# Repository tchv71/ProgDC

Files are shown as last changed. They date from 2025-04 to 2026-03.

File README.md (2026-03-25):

## Программируемый дешифратор (MMU) для Пальмиры

Прототипом послужил программируемый дешифратор для Радио 86-РК, описанный в журналах "Радио" 1994, №3-5. 

[https://archive.radio.ru/web/1994/03/020/]: https://archive.radio.ru/web/1994/03/020/

Общая идея конструктива - плата программируемого дешифратора вставляется в сокет процессора, а процессор (возможно, в виде z80card) вставляется в панельку на плате ПД. Дополнительные сигналы к/от платы Пальмиры выводятся на штырьковый разъем на правом краю платы ПД.

Внесены следующие усовершенствования:

1. Устранена зависимость от значений системного регистра при программировании устройства по адресу 0FFh. В оригинальном устройстве запись по адресу 0FFh меняла и значение системного регистра, и ОЗУ дешифратора. Это налагало ограничение на значения, которые можно записать в порт 0FFh и усложняло программирование. Теперь эти порты схемотехнически разделены - если было предварительное чтение из порта 0FFh, запись будет в системный регистр, в противном случае - в ОЗУ дешифратора.
2. Используются все биты ОЗУ дешифратора, старшие 4 бита используются для расширения адреса системного ОЗУ. Поддерживается до 512К системного ОЗУ. Поддерживается 64 (максимум 128) кбайта ПЗУ.
3. Бит 4 ОЗУ дешифратора более не используется как признак "только чтение", вместо него используется значение 3 номера линии устройства.
4. Поддерживается бит 0 байта расширения конфигурации Пальмиры, включающий теневое ОЗУ по адресам 0-7FFFh.
5. Поддерживается до 4-х конфигураций дешифратора, которые выбираются битами 4-3 системного регистра. Таким образом, для того, чтобы изменить конфигурацию памяти, нет необходимости менять её постранично, можно запрограммировать новую конфигурацию заранее, а потом мгновенно применить её одной запись в порт 0FFh.
6. Поддерживается процессор Z80 в формате z80-card. 580ВМ80А также поддерживается, совместно с системным контроллером 580ВК38
7. Вместо микросхемы КР537РУ10 применена IDC6116SA45P как более быстродействующая, изменены тайминги сигнала записи в нее для повышения надежности записи.

## Системный регистр (in/out 0FFh)

|Бит|Обозначение|Биты управления режимом|
|-|-|-|
|7|Q7|Работа|
|6|Q6|Программирование портов ввода-вывода|
|5|Q5|Программирование конфигурации памяти|
|4||Биты выбора конфигурации (запись) Бит1|
|3||Биты выбора конфигурации (запись) Бит0|
|2||Биты выбора конфигурации (чтение) Бит1|
|1||Биты выбора конфигурации (чтение) Бит0|
|0||свободно|

Чтобы записать в системный регистр, надо сначала из него прочитать. Первая запись после чтения по адресу 0FFh будет в системный регистр, все последующие - в ОЗУ дешифратора (в режиме программирования) или в порт в рабочем режиме.

## Назначение линий выхода дешифратора ИД3:

|Номер линии|Адрес в Пальмире|Устройство|
|-|-|-|
|0|0C200h|ВВ55 контроллер клавиатуры|
|1|0C400h|ВВ55 дополнительный контроллер|
|2|0C000h|ВГ75 контроллер дисплея|
|3|-|ОЗУ только чтение|
|4|0E000h|ПЗУ|
|5|0000h|ОЗУ первые 32кб|
|6|0CC00h|ВИ53-1|
|7|0C600h|ВТ57/ВТ37|
|8|0C800h|ВИ53-2|
|9|||
|10|0D800h|ОЗУ ЗГ РУ10|
|11|0CE00h|Palmira ext. byte|
|12|0C300h|FT245R port|
|13|8000h|ОЗУ вторые 32кб|
|14|0CA00h|VDP TMS9918A|
|15|0F700h|Страница контроллеров RK60k|

Линия 15 задает положения страницы контроллеров RK60k размером 256 байт. Контроллеры имеют следующие фиксированные относительные адреса:

|Номер|Контроллер|Адрес|
|-|-|-|
|0|FDC |0F700h; 1793 floppy disk controller|
|1|INTR|0F720h; 8259 interrupt controller |
|2|PSG1|0F740h; 8253 first	 |
|3|PSG2|0F760h; 8253 second	 	 |
|4|PPI |0F780h; 8255 fist		 |
|5|PPI2|0F7A0h; 8255 second	 	  |
|6|DISP|0F7C0h; 8275 display adapter	 |
|7|DMA |0F7E0h; 8257 DMA chip	 	 |

Поскольку одна конфигурация занимает 512 байт в ОЗУ дешифратора, появляется возможность хранить 4 конфигурации и мгновенно переключать их битами 3 и 4 системного регистра.

## ПЗУ 556РТ4

| Бит адреса | Сигнал |
| --- | --- |
| A3 | Q7 |
| A2 | Q6 |
| A1 | Q5 |
| A0 | In/Out |

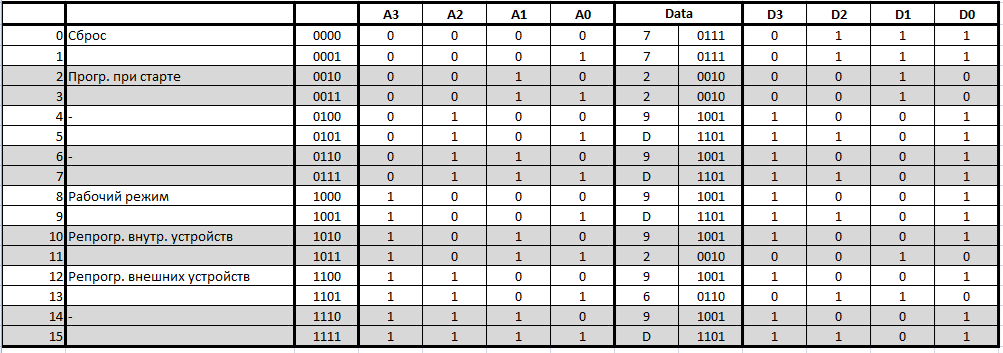
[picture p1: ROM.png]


## Ошибки в печатных платах:

### Версия 1.4:

1. На микросхему D10 6116SA45P не заведено питание и земля.
2. Вывод 8 В14.3 К555ЛА3 должен быть подключен к выводу 15 D9 КР556РТ4, а вывод 4 D9 - к земле.

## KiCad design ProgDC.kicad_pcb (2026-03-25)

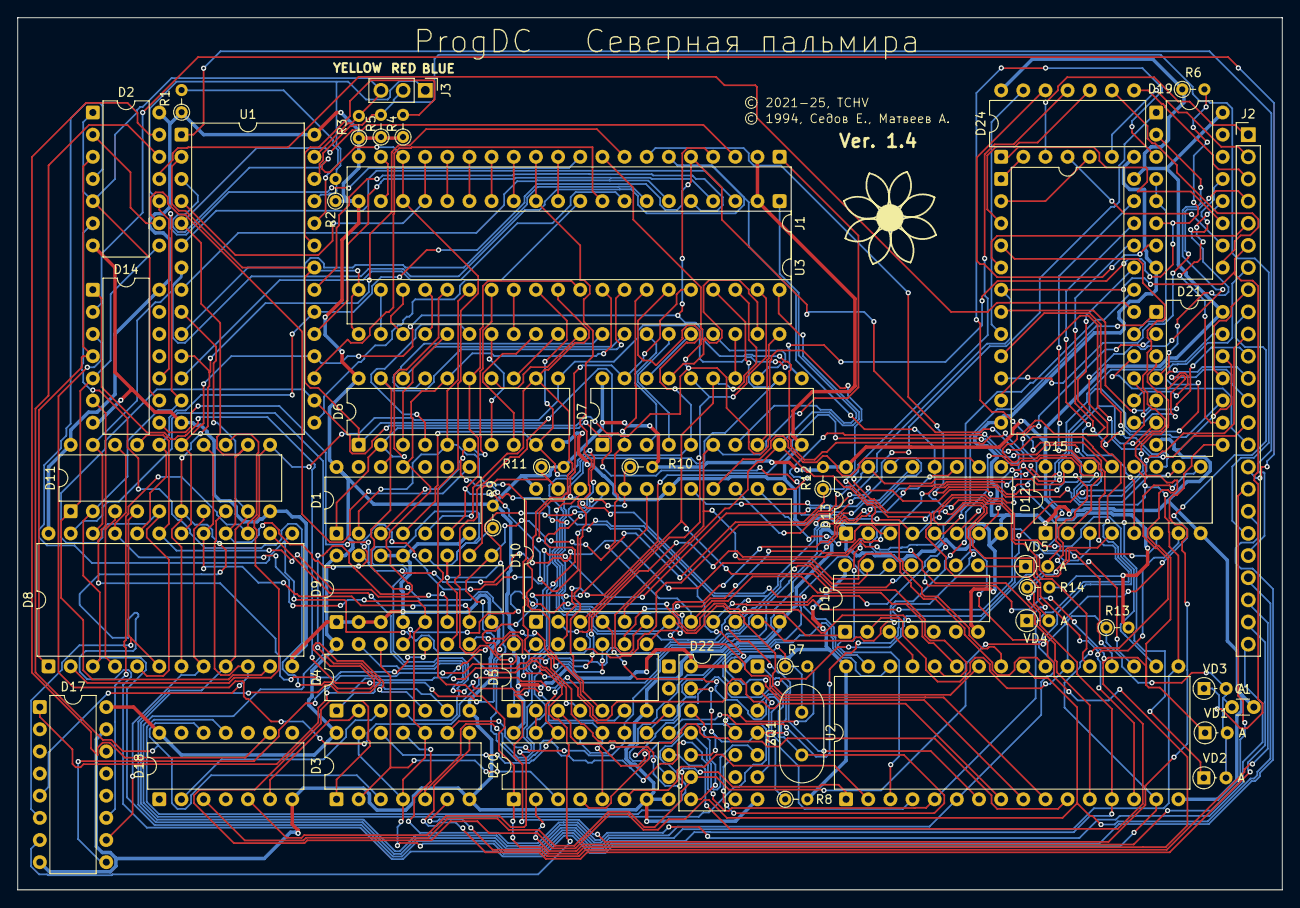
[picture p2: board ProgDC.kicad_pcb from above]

Board: 2 copper layers, 145.0 x 100.0 mm, 51 parts (1 on the bottom side), 179 nets.

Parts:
C1: 470; C_Disc_D3.0mm_W1.6mm_P2.50mm
D1: K155LA2; DIP-14_W7.62mm
D2, D4, D16: 133LL1; DIP-14_W7.62mm
D3, D20, D24: 133LI1; DIP-14_W7.62mm
D5, D22: 133LN1; DIP-14_W7.62mm
D6, D7, D11: 1533ИР22; DIP-20_W7.62mm
D8: К589ИР12; DIP-24_W15.24mm
D9: КР556РТ4; DIP-16_W7.62mm
D10: КР537РУ10; DIP-24_W15.24mm
D12, D13: K589АП16; DIP-16_W7.62mm
D14: 133LA3; DIP-14_W7.62mm
D15: 155ID3; DIP-24_W15.24mm
D17: КР1533КП11; DIP-16_W7.62mm
D18, D23: 555TM2; DIP-14_W7.62mm
D19: 74AC138(COMB); DIP-16_W7.62mm
D21: 74HC86N; DIP-14_W7.62mm
J1: Conn_02x20_Counter_Clockwise_MountingPin; DIP-40_W15.24mm
J2: Conn_01x24_Pin; PinHeader_1x24_P2.54mm_Vertical
J3: Conn_01x03_Pin; PinHeader_1x03_P2.54mm_Vertical
R1, R2, R3, R4, R5, R6, R9, R10, R11, R12, R13, R14: R0125; R_Axial_DIN0204_L3.6mm_D1.6mm_P2.54mm_Vertical
R7, R8: R0125H; R_Axial_DIN0204_L3.6mm_D1.6mm_P2.54mm_Vertical
U1: KR580VK28; DIP-28_W15.24mm
U2: 628512; DIP-32_W15.24mm
U3: CPU; DIP-40_W15.24mm
VD1, VD2, VD3, VD4, VD5: 1N4148; D_DO-34_SOD68_P2.54mm_Vertical_AnodeUp
ZQ1: QUARTZ; Crystal_HC18-U_Vertical

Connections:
+5V: D1.14 (VCC), D2.14 (VCC), D3.14 (VCC), D4.14 (VCC), D5.14 (VCC), D6.20 (VCC), D7.20 (VCC), D8.24 (VCC), D9.16 (+5V), D10.24 (VCC), D11.20 (VCC), D12.16 (VCC), D13.16 (VCC), D14.14 (VCC), D15.24 (VCC), D16.14 (VCC), D17.16 (VCC), D18.14 (VCC), D19.16 (VCC), D20.14 (VCC), D21.14 (VCC), D22.14 (VCC), D23.14 (VCC), D24.14 (VCC), J1.20, R1.1 (TOP), R2.1 (TOP), R3.1 (TOP), R4.1 (TOP), R5.1 (TOP), R6.1 (TOP), R8.2, R9.2 (BOT), R10.2 (BOT), R11.2 (BOT), R12.2 (BOT), R13.2 (BOT), R14.2 (BOT), U1.28 (VCC), U2.32 (VCC), U3.20 (VCC)
/8MHZ: D18.11 (C), D23.5 (Q), D23.11 (C)
/"1": D6.11 (PE), D7.11 (PE), D8.2 (MD), D11.11 (PE), D19.6 (E1), R6.2 (BOT)
/+12V: J1.28, U3.28 (+12V)
/-5V: J1.11, U3.11 (-5V)
/A0: D6.3 (D0), U3.25 (A0)
/A1: D6.4 (D1), U3.26 (A1)
/A2: D6.7 (D2), U3.27 (A2)
/A3: D6.8 (D3), U3.29 (A3)
/A4: D6.13 (D4), U3.30 (A4)
/A5: D6.14 (D5), U3.31 (A5)
/A6: D6.17 (D6), U3.32 (A6)
/A7: D6.18 (D7), U3.33 (A7)
/A8: D7.3 (D0), U3.34 (A8)
/A9: D7.4 (D1), U3.35 (A9)
/A10: D7.7 (D2), U3.1 (A10)
/A11: D7.8 (D3), U3.40 (A11)
/A12: D7.13 (D4), U3.37 (A12)
/A13: D7.14 (D5), U3.38 (A13)
/A14: D7.17 (D6), U3.39 (A14)
/A15: D7.18 (D7), U3.36 (A15)
/AB0: D1.1, D6.2 (Q0), J1.25, U2.12 (A0)
/AB1: D1.2, D6.5 (Q1), J1.26, U2.11 (A1)
/AB2: D1.3, D6.6 (Q2), J1.27, U2.10 (A2)
/AB3: D1.4, D6.9 (Q3), J1.29, U2.9 (A3)
/AB4: D1.5, D6.12 (Q4), J1.30, U2.8 (A4)
/AB5: D1.6, D6.15 (Q5), D19.1 (0), J1.31, U2.7 (A5)
/AB6: D1.11, D6.16 (Q6), D19.2 (1), J1.32, U2.6 (A6)
/AB7: D1.12, D6.19 (Q7), D19.3 (2), J1.33, U2.5 (A7)
/AB8: D7.2 (Q0), D10.8 (A10), J1.34, U2.27 (A8)
/AB9: D7.5 (Q1), D10.7 (A9), J1.35, U2.26 (A9)
/AB10: D7.6 (Q2), D10.6 (A8), J1.1, U2.23 (A10)
/AB11: D7.9 (Q3), D10.5 (A7), J1.40, U2.25 (A11)
/AB12: D7.12 (Q4), D10.4 (A6), J1.37, U2.4 (A12)
/AB13: D7.15 (Q5), D10.3 (A5), J1.38, U2.28 (A13)
/AB14: D7.16 (Q6), D10.2 (A4), J1.39
/AB15: D7.19 (Q7), D10.1 (A3), J1.36, U2.31 (A15)
/ARR16: D20.6 (Y), U2.2 (A16)
/ARR17: D20.8 (Y), U2.30 (A17)
/ARR18: D20.11 (Y), U2.1 (A18)
/C1: J1.22, U3.22 (C1)
/C2: J1.15, U3.15 (C2)
/C800_VI53_2: D5.13 (A), D21.8 (Y)
/CLK: D18.3 (C), D23.9 (Q), J2.9
/CS_RAMR: D16.12 (A), D22.6 (Y)
/D0: U1.15 (D0), U3.10 (D0)
/D1: U1.17 (D1), U3.9 (D1)
/D2: U1.12 (D2), U3.8 (D2)
/D3: U1.10 (D3), U3.7 (D3)
/D4: U1.6 (D4), U3.3 (D4)
/D5: U1.19 (D5), U3.4 (D5)
/D6: U1.21 (D6), U3.5 (D6)
/D7: U1.8 (D7), U3.6 (D7)
/DB0: D8.3 (D0), D11.2 (Q0), D12.4 (DI0), J1.10, U1.13 (DB0), U2.13 (D0)
/DB1: D8.5 (D1), D11.5 (Q1), D12.7 (DI1), J1.9, U1.16 (DB1), U2.14 (D1)
/DB2: D8.7 (D2), D11.6 (Q2), D12.9 (DI2), J1.8, U1.11 (DB2), U2.15 (D2)
/DB3: D8.9 (D3), D11.9 (Q3), D12.12 (DI3), J1.7, U1.9 (DB3), U2.17 (D3)
/DB4: D8.16 (D4), D11.12 (Q4), D13.4 (DI0), J1.3, U1.5 (DB4), U2.18 (D4)
/DB5: D8.18 (D5), D11.15 (Q5), D13.7 (DI1), J1.4, U1.18 (DB5), U2.19 (D5)
/DB6: D8.20 (D6), D11.16 (Q6), D13.9 (DI2), J1.5, U1.20 (DB6), U2.20 (D6)
/DB7: D8.22 (D7), D11.19 (Q7), D13.12 (DI3), J1.6, U1.7 (DB7), U2.21 (D7)
/DBIN: J1.17, U1.4 (DBIN), U3.17 (RC)
/HLD: J1.13, U3.13 (HLD)
/HLDA: D5.1 (A), D6.1 (~EO), D7.1 (~EO), J1.21, U1.2 (HLDA), U1.22 (BUSEN), U3.21 (HLDA)
/INT: J1.14, U3.14 (INT)
/INTE: J1.16, U3.16 (INTE)
/P0: D4.4 (A), D9.12 (D0), R9.1 (TOP)
/P1: D4.9 (A), D9.11 (D1), D10.20 (~OE), R10.1 (TOP)
/P2: D9.10 (D2), D10.23 (A2), R11.1 (TOP)
/P3: D9.9 (D3), D12.15 (~CE), D13.15 (~CE), D17.1 (SEL), R12.1 (TOP)
/Q0: D8.4 (Q0), D11.3 (D0)
/Q1: D8.6 (Q1), D11.4 (D1), D17.6 (2B)
/Q2: D8.8 (Q2), D11.7 (D2), D17.10 (3B)
/Q3: D8.10 (Q3), D11.8 (D3), D17.5 (2A)
/Q4: D8.15 (Q4), D11.13 (D4), D17.11 (3A)
/Q5: D8.17 (Q5), D9.7 (A2), D11.14 (D5)
/Q6: D8.19 (Q6), D9.6 (A1), D11.17 (D6)
/Q7: D3.4 (A), D3.10 (B), D3.13 (B), D8.21 (Q7), D9.5 (A0), D11.18 (D7), J2.18
/R0: D12.2 (DO0), D15.23 (1)
/R1: D12.5 (DO1), D15.22 (2)
/R2: D12.11 (DO2), D15.21 (4)
/R3: D12.14 (DO3), D15.20 (8)
/R4: D13.2 (DO0), U2.3 (A14)
/R5: D3.5 (B), D13.5 (DO1), D21.1 (A)
/R6: D3.9 (A), D13.11 (DO2), D20.9 (A)
/R7: D3.12 (A), D13.14 (DO3), D20.12 (A)
/R8: D14.3 (Y), D22.3 (A)
/RAM_SEL: D14.2 (B), J2.16
/RDY: J1.23, U3.23 (RDY)
/RESET: D5.5 (A), J1.12, U3.12 (RST)
/ROM_A13: D3.6 (Y), J2.22
/ROM_A14: D3.8 (Y), J2.23
/ROM_A15: D3.11 (Y), J2.24
/STSTB: J2.20, U1.1 (STSTB)
/SYN: J1.19, U3.19 (SYN)
/WI: J1.24, U3.24 (WI)
/~A_FF: D1.8, D2.2 (B), D2.9 (A)
/~C100_SD_CNTR: D15.10 (9), J2.4
/~C200_PPI1_: D24.3 (Y), J2.1
/~C200_PPI1: D15.1 (0), D24.2 (B)
/~C300: D15.14 (12), J2.13
/~C400_PPI2_: D24.6 (Y), J2.2
/~C400_PPI2: D15.2 (1), D24.5 (B)
/~C500_VDP: D15.16 (14), J2.15
/~C800_VI53_2_: D5.12 (Y), J2.10
/~C800_VI53_2: D15.9 (8), D21.10 (B)
/~CC00_VI53_1_: D5.8 (Y), J2.7
/~CC00_VI53_1: D15.7 (6), D21.5 (B)
/~CE00: D15.13 (11), J2.12
/~CS_628512: C1.1, D16.2 (B), R13.1 (TOP), U2.22 (CS), VD1.2 (A), VD2.2 (A), VD3.2 (A)
/~CS_D800: D15.11 (10), J2.14
/~CS_DMA_2: D21.11 (Y), J2.8
/~CS_DMA_: D24.11 (Y), VD4.1 (K)
/~CS_DMA: D15.8 (7), D24.13 (B)
/~CS_RAMR: D15.4 (3), D16.10 (B), D22.5 (A), VD1.1 (K)
/~CS_ROM: D15.5 (4), J2.5
/~CS_SRAM_8000: D15.15 (13), J2.11, VD2.1 (K)
/~CS_VG75_: D24.8 (Y), J2.3
/~CS_VG75: D15.3 (2), D24.10 (B)
/~D15_CS1: D4.8 (Y), D15.19 (&C)
/~D15_CS2: D2.11 (Y), D15.18 (C)
/~F700: D15.17 (15), D19.4 (~E2), D19.5 (~E3)
/~INTA: R4.2 (BOT), U1.23 (INTA)
/~I/OR: D2.10 (B), D14.10 (B), J3.1, R2.2 (BOT), U1.25 (I/OR)
/~I/OW: D2.1 (A), D2.5 (B), D14.9 (A), J3.3, R3.2 (BOT), U1.27 (I/OW)
/~MEMR: R1.2 (BOT), U1.24 (MEMR)
/~MEMW_VT57: D20.2 (B), J2.17
/~MEMW: J2.19, J3.2, R5.2 (BOT), U1.26 (MEMW)
/~MWR: D3.2 (B), D4.12 (A), D20.3 (Y)
/~RAM_MAIN: D5.11 (A), D15.6 (5), J2.6, VD3.1 (K)
/~RD: D3.1 (A), J2.21, U2.24 (RD)
/~RESET: D5.6 (Y), D8.14 (RES)
/~WE_628512: D4.11 (Y), D16.1 (A)
/~WR: D16.9 (A), D20.1 (A), J1.18, U1.3 (WR), U3.18 (TR)
GND: C1.2, D1.7 (GND), D2.7 (GND), D3.7 (GND), D4.7 (GND), D5.7 (GND), D6.10 (GND), D7.10 (GND), D8.12 (GND), D9.1 (A6), D9.2 (A5), D9.3 (A4), D9.4 (A3), D9.8 (GND), D9.13 (~CS1), D9.14 (~CS2), D10.12 (GND), D10.18 (~CS), D11.10 (GND), D12.1 (~CS), D12.8 (GND), D13.1 (~CS), D13.8 (GND), D14.7 (GND), D15.12 (GND), D16.7 (GND), D17.8 (GND), D17.15 (~OE), D18.7 (GND), D19.8 (GND), D20.7 (GND), D21.7 (GND), D21.12 (A), D22.7 (GND), D23.7 (GND), D24.7 (GND), J1.2, U1.14 (GND), U2.16 (GND), U3.2 (GND)
unnamed: D2.4 (A), D5.4 (Y), D8.13 (CS2)
unnamed: D2.6 (Y), D4.5 (B)
unnamed: D4.1 (A), D4.6 (Y)
unnamed: D5.3 (A), D8.23 (S1)
unnamed: D10.19 (A0), D17.9 (3Y)
unnamed: D10.22 (A1), D17.7 (2Y)
unnamed: D10.9 (D0), D12.3 (DB0)
unnamed: D10.10 (D1), D12.6 (DB1)
unnamed: D10.11 (D2), D12.10 (DB2)
unnamed: D10.13 (D3), D12.13 (DB3)
unnamed: D10.14 (D4), D13.3 (DB0)
unnamed: D10.15 (D5), D13.6 (DB1)
unnamed: D10.16 (D6), D13.10 (DB2)
unnamed: D10.17 (D7), D13.13 (DB3)
unnamed: D10.21 (~WE), D18.5 (Q)
unnamed: D2.8 (Y), D8.11 (EV), D11.1 (~EO), D14.5 (B)
unnamed: D5.10 (Y), D14.1 (A)
unnamed: D2.3 (Y), D8.1 (CS1), D14.4 (A)
unnamed: D4.10 (B), D14.6 (Y)
unnamed: D9.15 (A7), D14.8 (Y), D16.13 (B)
unnamed: D16.3 (Y), U2.29 (WR)
unnamed: D16.8 (Y), VD5.1 (K)
unnamed: D4.13 (B), D16.11 (Y)
unnamed: D4.3 (Y), D18.2 (D)
unnamed: D4.2 (B), D18.6 (~Q)
unnamed: D2.12 (A), D3.3 (Y), D18.12 (D)
unnamed: D2.13 (B), D18.9 (Q)
unnamed: D19.12 (3), D21.9 (A)
unnamed: D19.11 (4), D24.1 (A)
unnamed: D19.10 (5), D24.4 (A)
unnamed: D19.9 (6), D24.9 (A)
unnamed: D20.4 (A), D21.3 (Y)
unnamed: D5.2 (Y), D20.5 (B), D20.10 (B), D20.13 (B)
unnamed: D21.2 (B), D22.4 (Y)
unnamed: D19.13 (2), D21.4 (A)
unnamed: D5.9 (A), D21.6 (Y)
unnamed: D21.13 (B), R14.1 (TOP), VD4.2 (A), VD5.2 (A)
unnamed: D22.11 (A), D22.12 (Y), R7.2
unnamed: D22.10 (Y), D23.3 (C), ZQ1.1
unnamed: D22.13 (A), R7.1, ZQ1.2
unnamed: D23.2 (D), D23.6 (~Q)
unnamed: D23.1 (~R), D23.4 (~S), D23.10 (~S), D23.13 (~R)
unnamed: D23.8 (~Q), D23.12 (D)
unnamed: D19.7, D24.12 (A)

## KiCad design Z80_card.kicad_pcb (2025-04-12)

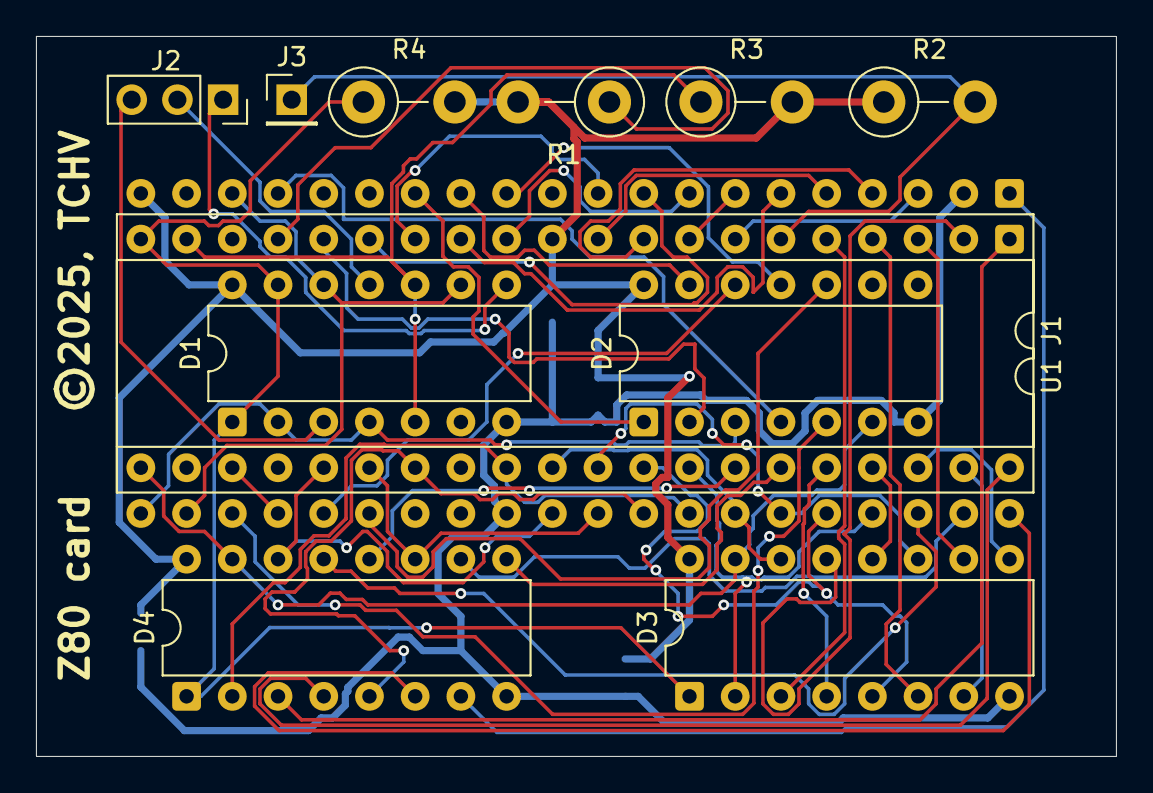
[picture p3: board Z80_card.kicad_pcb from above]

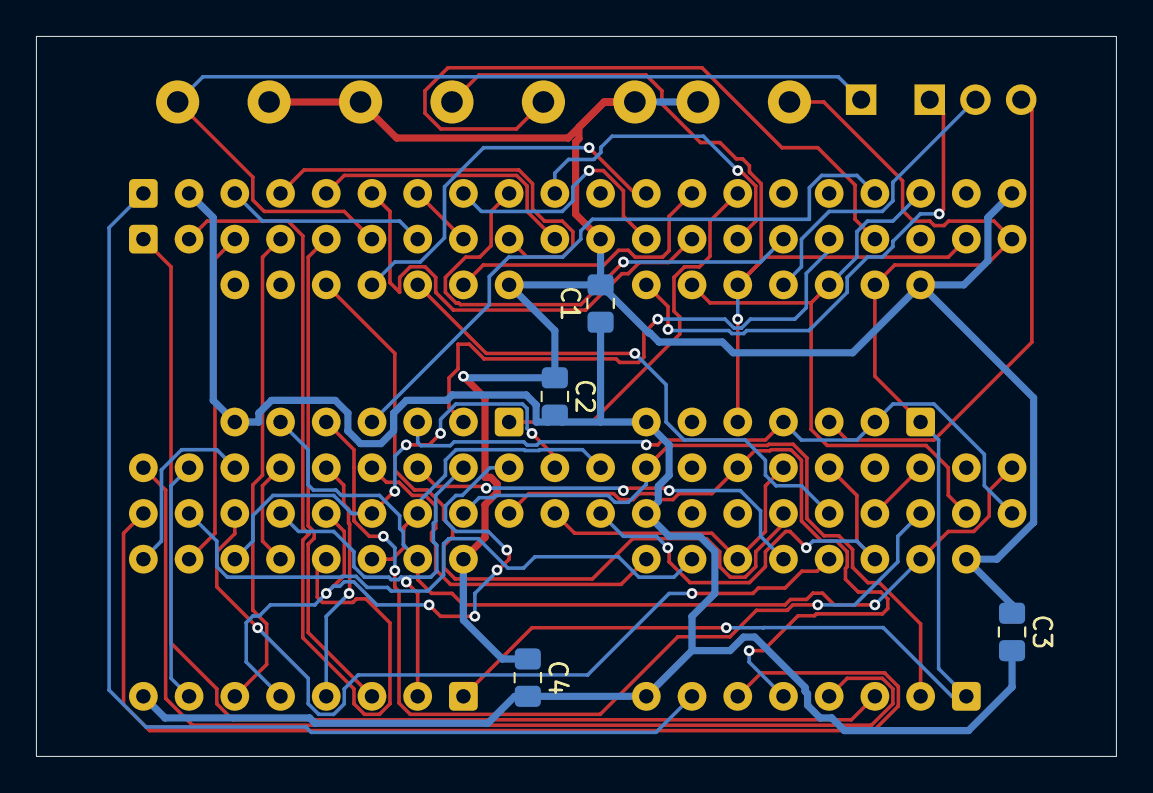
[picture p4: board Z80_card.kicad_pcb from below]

Board: 2 copper layers, 60.0 x 40.0 mm, 16 parts (4 on the bottom side), 53 nets.

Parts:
C1, C2, C3, C4: C; C_0805_2012Metric_Pad1.18x1.45mm_HandSolder
D1: 133LL1; DIP-14_W7.62mm
D2: 133LN1; DIP-14_W7.62mm
D3, D4: КР1533КП11; DIP-16_W7.62mm
J1: Conn_02x20_Counter_Clockwise_MountingPin; DIP-40_W15.24mm
J2: Conn_01x03_Pin; PinSocket_1x03_P2.54mm_Vertical
J3: Conn_01x01_Pin; PinHeader_1x01_P2.54mm_Vertical
R1, R2, R3, R4: R0125; R_Axial_DIN0411_L9.9mm_D3.6mm_P5.08mm_Vertical
U1: Z84C00-4SC; DIP-40_W15.24mm

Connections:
+5V: C1.2, C2.1, C3.1, C4.1, D1.14 (VCC), D2.14 (VCC), D3.16 (VCC), D4.16 (VCC), J1.20, R1.2 (BOT), R2.1 (TOP), R3.2 (BOT), R4.2 (BOT), U1.11 (VCC)
/A0: D4.14 (4A), J1.25, U1.30 (A0)
/A1: D4.11 (3A), J1.26, U1.31 (A1)
/A2: D4.5 (2A), J1.27, U1.32 (A2)
/A3: D4.2 (1A), J1.29, U1.33 (A3)
/A4: D3.14 (4A), J1.30, U1.34 (A4)
/A5: D3.11 (3A), J1.31, U1.35 (A5)
/A6: D3.5 (2A), J1.32, U1.36 (A6)
/A7: D3.2 (1A), J1.33, U1.37 (A7)
/A8: D4.12 (4Y), J1.34
/A9: D4.9 (3Y), J1.35
/A10: D4.7 (2Y), J1.1
/A11: D4.4 (1Y), J1.40
/A12: D3.12 (4Y), J1.37
/A13: D3.9 (3Y), J1.38
/A14: D3.7 (2Y), J1.39
/A15: D3.4 (1Y), J1.36
/BLUE: D1.3 (Y), J2.3
/CLK: J3.1, R2.2 (BOT), U1.6 (CLK)
/D0: J1.10, U1.14 (D0)
/D1: J1.9, U1.15 (D1)
/D2: J1.8, U1.12 (D2)
/D3: J1.7, U1.8 (D3)
/D4: J1.3, U1.7 (D4)
/D5: J1.4, U1.9 (D5)
/D6: J1.5, U1.10 (D6)
/D7: J1.6, U1.13 (D7)
/DBIN: D2.4 (Y), J1.17
/HLD: D2.13 (A), J1.13
/INT: D2.1 (A), J1.14
/RDY: J1.23, U1.24 (~WAIT)
/RED: D1.8 (Y), J2.1
/RESET: D2.11 (A), J1.12
/YELLOW: D1.11 (Y), J2.2
/_A8: D4.13 (4B), U1.38 (A8)
/_A9: D4.10 (3B), U1.39 (A9)
/_A10: D4.6 (2B), U1.40 (A10)
/_A11: D4.3 (1B), U1.1 (A11)
/_A12: D3.13 (4B), U1.2 (A12)
/_A13: D3.10 (3B), U1.3 (A13)
/_A14: D3.6 (2B), U1.4 (A14)
/_A15: D3.3 (1B), U1.5 (A15)
/_HLDA: D2.6 (Y), D3.15 (~OE), D4.15 (~OE), J1.21
/~RESET: D2.10 (Y), U1.26 (~RESET)
/~WR: D1.9 (A), D1.12 (A), J1.18, U1.22 (~WR)
GND: C1.1, C2.2, C3.2, C4.2, D1.7 (GND), D2.7 (GND), D3.8 (GND), D4.8 (GND), J1.2, U1.29 (GND)
unnamed: D1.1 (A), D1.13 (B), D3.1 (SEL), D4.1 (SEL), R4.1 (TOP), U1.20 (~IORQ)
unnamed: D1.2 (B), D1.4 (A), D2.3 (A), U1.21 (~RD)
unnamed: D1.5 (B), D1.10 (B), R3.1 (TOP), U1.19 (~MREQ)
unnamed: D2.2 (Y), U1.16 (~INT)
unnamed: D2.5 (A), U1.23 (~BUSACK)
unnamed: D2.12 (Y), U1.25 (~BUSREQ)
unnamed: R1.1 (TOP), U1.17 (~NMI)

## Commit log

2025-04-29 Fix address and data buffering
    [ProgDC.kicad_pcb, ProgDC.kicad_sch, Z80_card.kicad_sch]
2025-05-01 Ver. 1.4
    [ProgDC.kicad_pcb, ProgDC.kicad_sch]
2025-05-27 Fix layout
    [ProgDC.kicad_pcb]
2026-02-05 Update PCB
    [ProgDC.kicad_pcb, ProgDC.kicad_sch]
2026-02-06 Fix pcb
    [ProgDC.kicad_pcb]
2026-03-20 Fix bugs
    [ProgDC.kicad_pcb, ProgDC.kicad_sch]
2026-04-02 Add PSG select
    [ProgDC.kicad_sch]

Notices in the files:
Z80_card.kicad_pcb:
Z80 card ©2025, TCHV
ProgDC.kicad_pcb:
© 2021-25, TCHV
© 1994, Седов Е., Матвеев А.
